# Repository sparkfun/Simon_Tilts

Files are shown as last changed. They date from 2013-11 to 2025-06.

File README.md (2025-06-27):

Simon Tilts - Through Hole Soldering Kit
========================================

[Simon Tilts - Through Hole Soldering Kit  
*Simon Tilts - Through Hole Soldering (KIT-12634)*](https://www.sparkfun.com/products/12634)

This is a new take on the original Simon Says game. Instead of pressing buttons, the player is challenged to tilt the game in a specific pattern of rotations.

Repository Contents
-------------------

* **/Firmware** - Source code, an Arduino Sketch
* **/Hardware** - Eagle design files (Schematic and Board)

License Information
-------------------
The hardware is released under [Creative Commons Share-alike 3.0](http://creativecommons.org/licenses/by-sa/3.0/).  
The firmware is released under beerware license

Hardware author: Pete Lewis @ SparkFun Electonics  
Firmware original author: Pete Lewis @ SparkFun Electronics

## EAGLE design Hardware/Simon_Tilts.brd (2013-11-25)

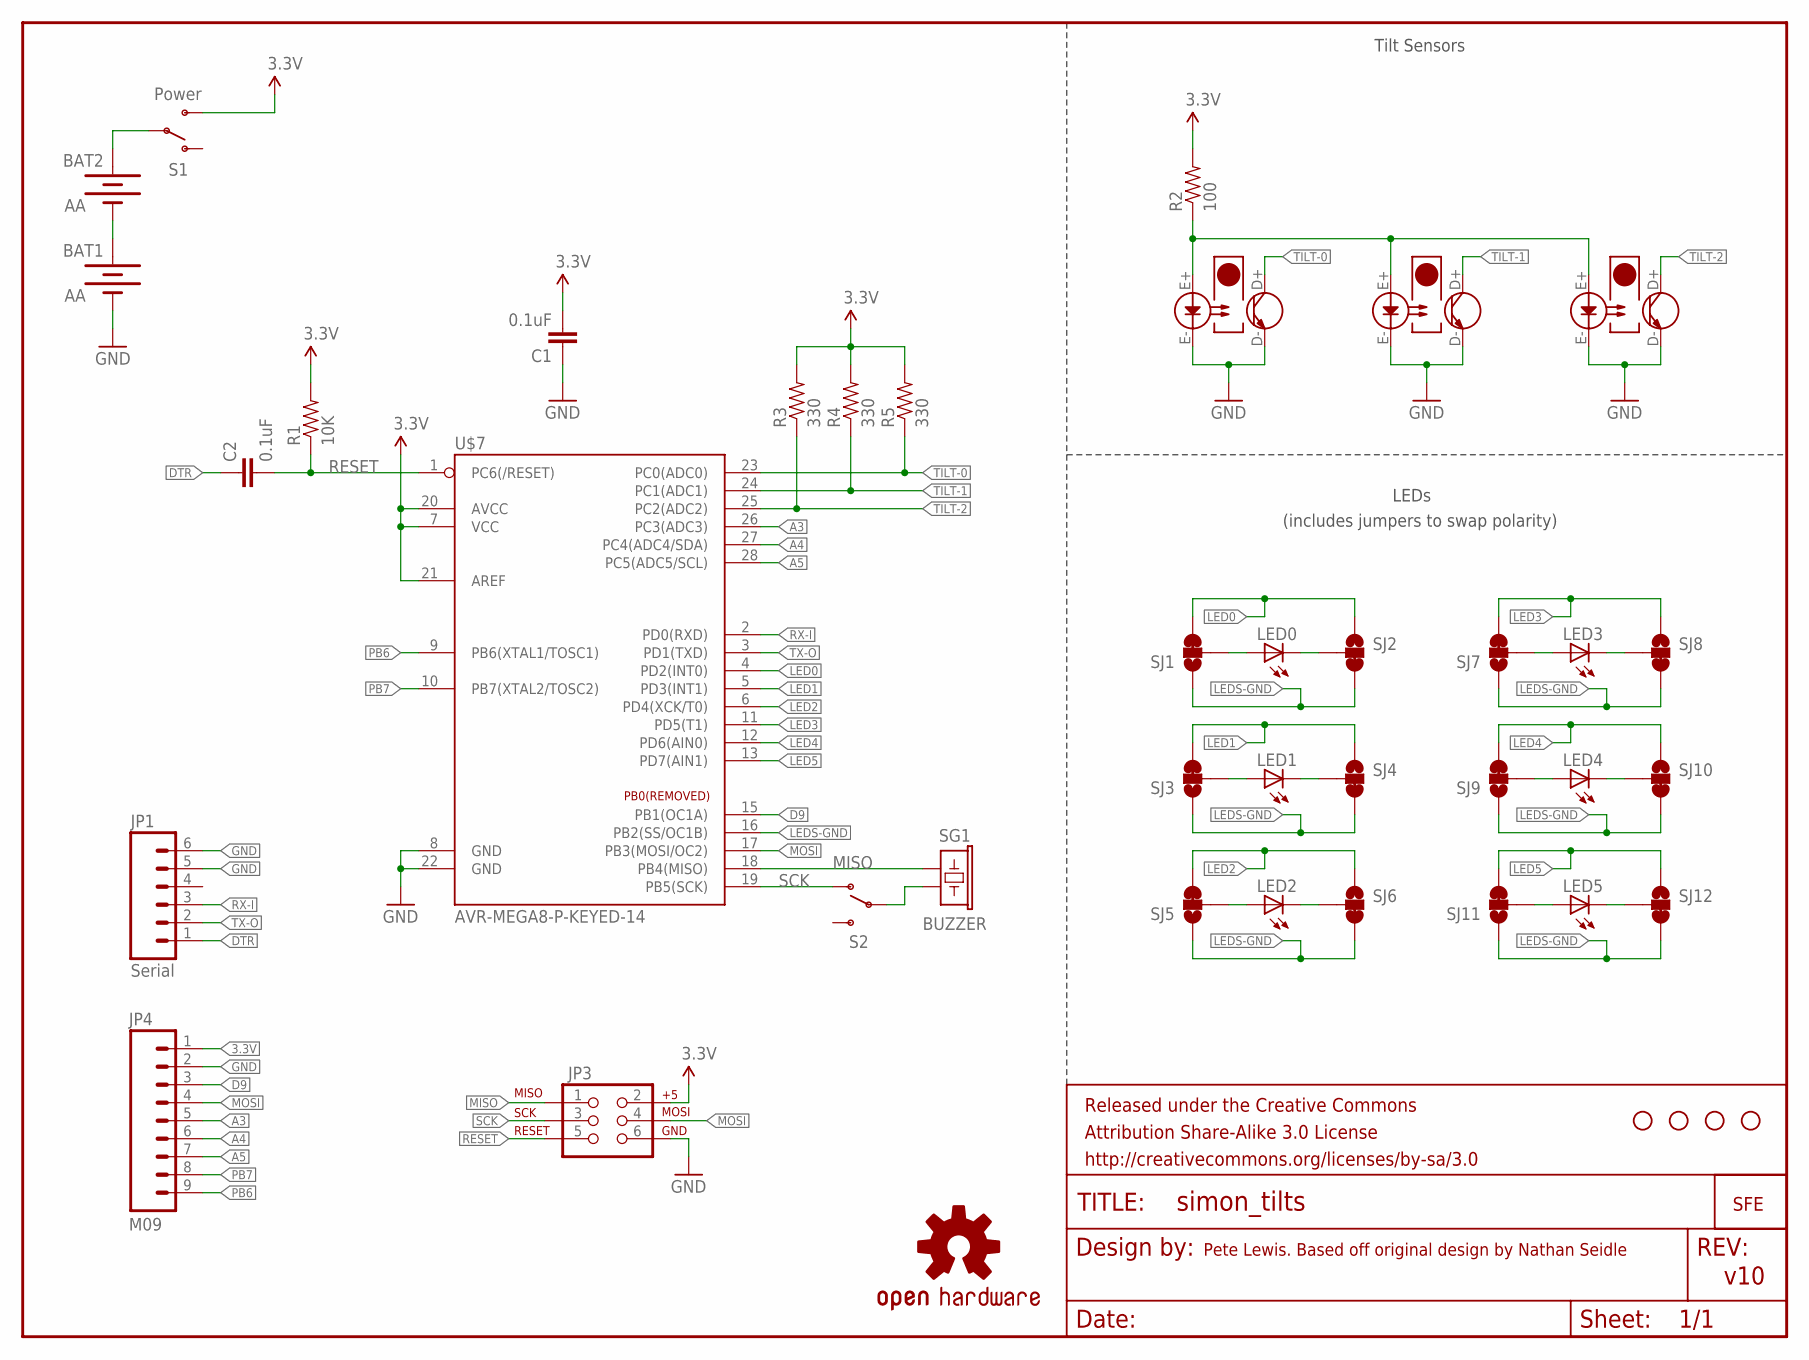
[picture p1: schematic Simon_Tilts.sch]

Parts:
BAT1, BAT2: AA; BATTERY-AA-KIT
C1, C2: 0.1uF; CAP-PTH-SMALL-KIT
FRAME1: FRAME-LETTER; CREATIVE_COMMONS
JP1: Serial; 1X06-NOSILK
JP2, JP5, JP6, JP7: STAND-OFF
JP3: AVR_SPI_PRG_6NS; 2X3-NS
JP4: M09; 1X09
LED0, LED1, LED2, LED3, LED4, LED5: LED5MM-KIT
R1: 10K; AXIAL-0.3-KIT
R2: 100; AXIAL-0.3-KIT
R3, R4, R5: 330; AXIAL-0.3-KIT
S1: Power; SWITCH-SPDT_KIT
S2: SWITCH-SPDTKIT; SWITCH-SPDT_KIT
SG1: BUZZER; BUZZER-12MM-KIT
SJ1, SJ2, SJ3, SJ4, SJ5, SJ6, SJ7, SJ8, SJ9, SJ10, SJ11, SJ12: SOLDERJUMPER_2WAYS; SJ_3
U$1: LOGO-SFENEW; SFE-NEW-WEBLOGO
U$3: OSHW-LOGOS; OSHW-LOGO-S
U$4, U$5, U$6: TILT_SENSORV5; TILT_SENSOR_V5
U$7: AVR-MEGA8-P-KEYED-14; DIL28-3_KEYED-14

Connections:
3.3V: C1.2, JP3.2, JP4.1, R1.P$2 (2), R2.P$2 (2), R3.P$2 (2), R4.P$2 (2), R5.P$2 (2), S1.3 (S), U$7.7 (VCC), U$7.20 (AVCC), U$7.21 (AREF)
A3: JP4.5, U$7.26 (PC3(ADC3))
A4: JP4.6, U$7.27 (PC4(ADC4/SDA))
A5: JP4.7, U$7.28 (PC5(ADC5/SCL))
D9: JP4.3, U$7.15 (PB1(OC1A))
DTR: C2.1, JP1.1
GND: BAT1.GND@1 (-), C1.1, JP1.5, JP1.6, JP3.6, JP4.2, U$4.D-, U$4.E-, U$5.D-, U$5.E-, U$6.D-, U$6.E-, U$7.8 (GND), U$7.22 (GND)
LED0: SJ1.3, SJ2.1, U$7.4 (PD2(INT0))
LED1: SJ3.3, SJ4.1, U$7.5 (PD3(INT1))
LED2: SJ5.3, SJ6.1, U$7.6 (PD4(XCK/T0))
LED3: SJ7.3, SJ8.1, U$7.11 (PD5(T1))
LED4: SJ9.3, SJ10.1, U$7.12 (PD6(AIN0))
LED5: SJ11.3, SJ12.1, U$7.13 (PD7(AIN1))
LEDS-GND: SJ1.1, SJ2.3, SJ3.1, SJ4.3, SJ5.1, SJ6.3, SJ7.1, SJ8.3, SJ9.1, SJ10.3, SJ11.1, SJ12.3, U$7.16 (PB2(SS/OC1B))
MISO: JP3.1, SG1.+ (1), U$7.18 (PB4(MISO))
MOSI: JP3.4, JP4.4, U$7.17 (PB3(MOSI/OC2))
unnamed: LED0.A, SJ1.2
unnamed: BAT2.PWR@1 (+), S1.2
unnamed: S2.2, SG1.- (2)
unnamed: BAT1.PWR@1 (+), BAT2.GND@1 (-)
unnamed: R2.P$1 (1), U$4.E+, U$5.E+, U$6.E+
unnamed: LED0.K (C), SJ2.2
unnamed: LED1.A, SJ3.2
unnamed: LED1.K (C), SJ4.2
unnamed: LED2.A, SJ5.2
unnamed: LED2.K (C), SJ6.2
unnamed: LED3.A, SJ7.2
unnamed: LED3.K (C), SJ8.2
unnamed: LED4.A, SJ9.2
unnamed: LED4.K (C), SJ10.2
unnamed: LED5.A, SJ11.2
unnamed: LED5.K (C), SJ12.2
PB6: JP4.9, U$7.9 (PB6(XTAL1/TOSC1))
PB7: JP4.8, U$7.10 (PB7(XTAL2/TOSC2))
RESET: C2.2, JP3.5, R1.P$1 (1), U$7.1 (PC6(/RESET))
RX-I: JP1.3, U$7.2 (PD0(RXD))
SCK: JP3.3, S2.1 (O), U$7.19 (PB5(SCK))
TILT-0: R5.P$1 (1), U$4.D+, U$7.23 (PC0(ADC0))
TILT-1: R4.P$1 (1), U$5.D+, U$7.24 (PC1(ADC1))
TILT-2: R3.P$1 (1), U$6.D+, U$7.25 (PC2(ADC2))
TX-O: JP1.2, U$7.3 (PD1(TXD))

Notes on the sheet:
v10
Pete Lewis. Based off original design by Nathan Seidle
Tilt Sensors
LEDs
(includes jumpers to swap polarity)

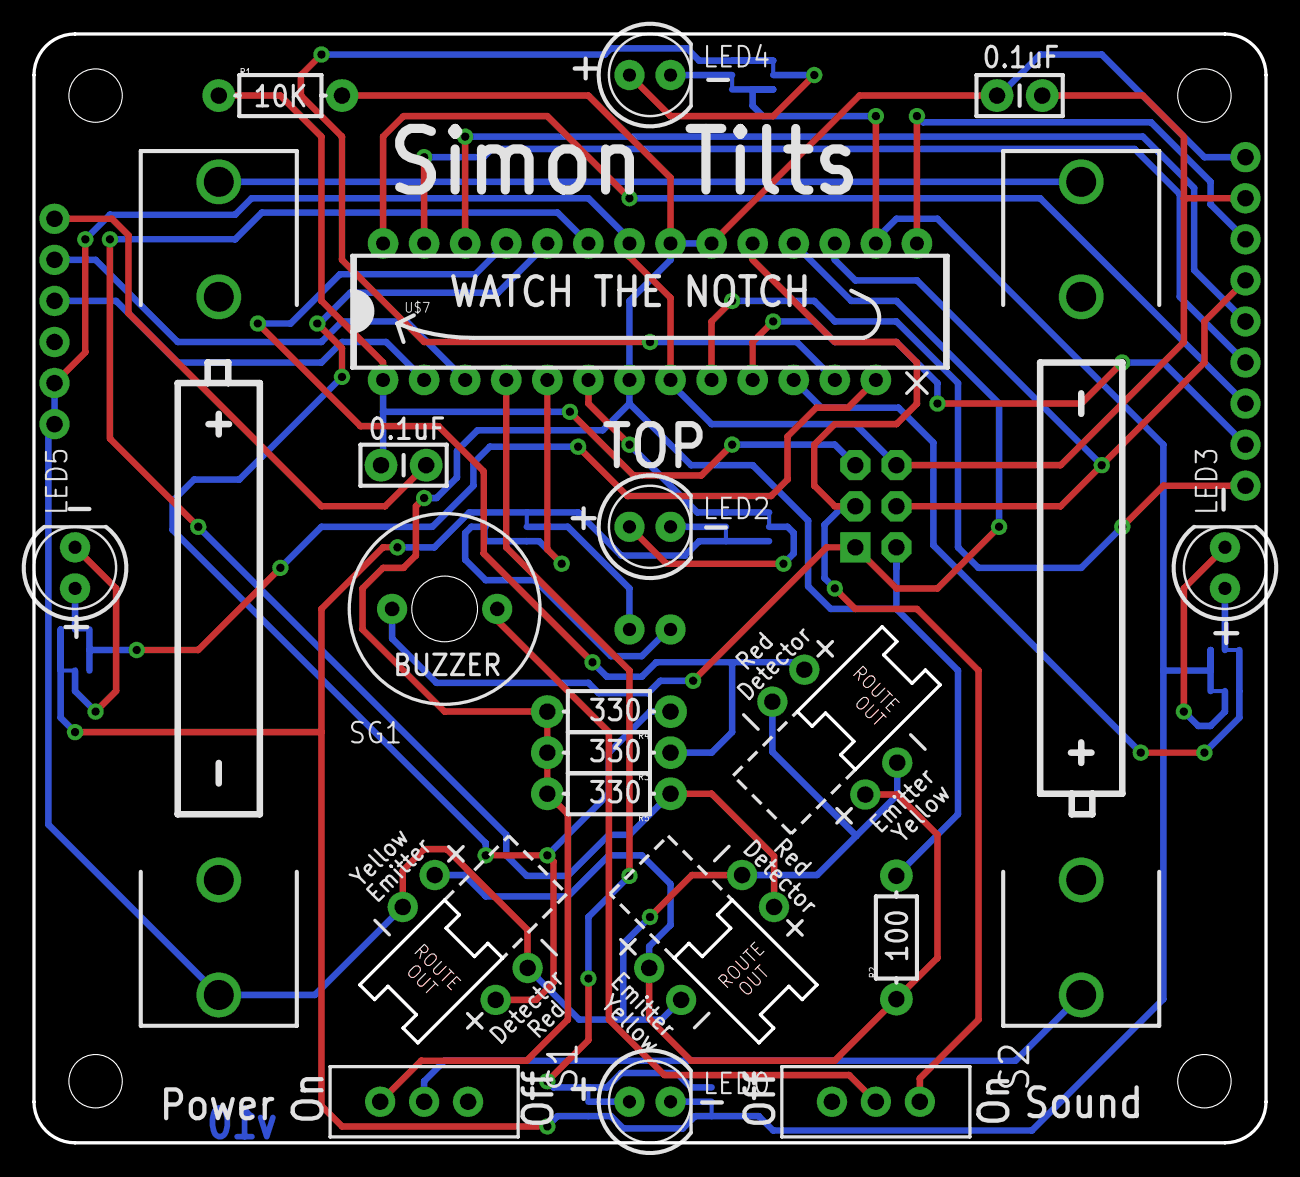
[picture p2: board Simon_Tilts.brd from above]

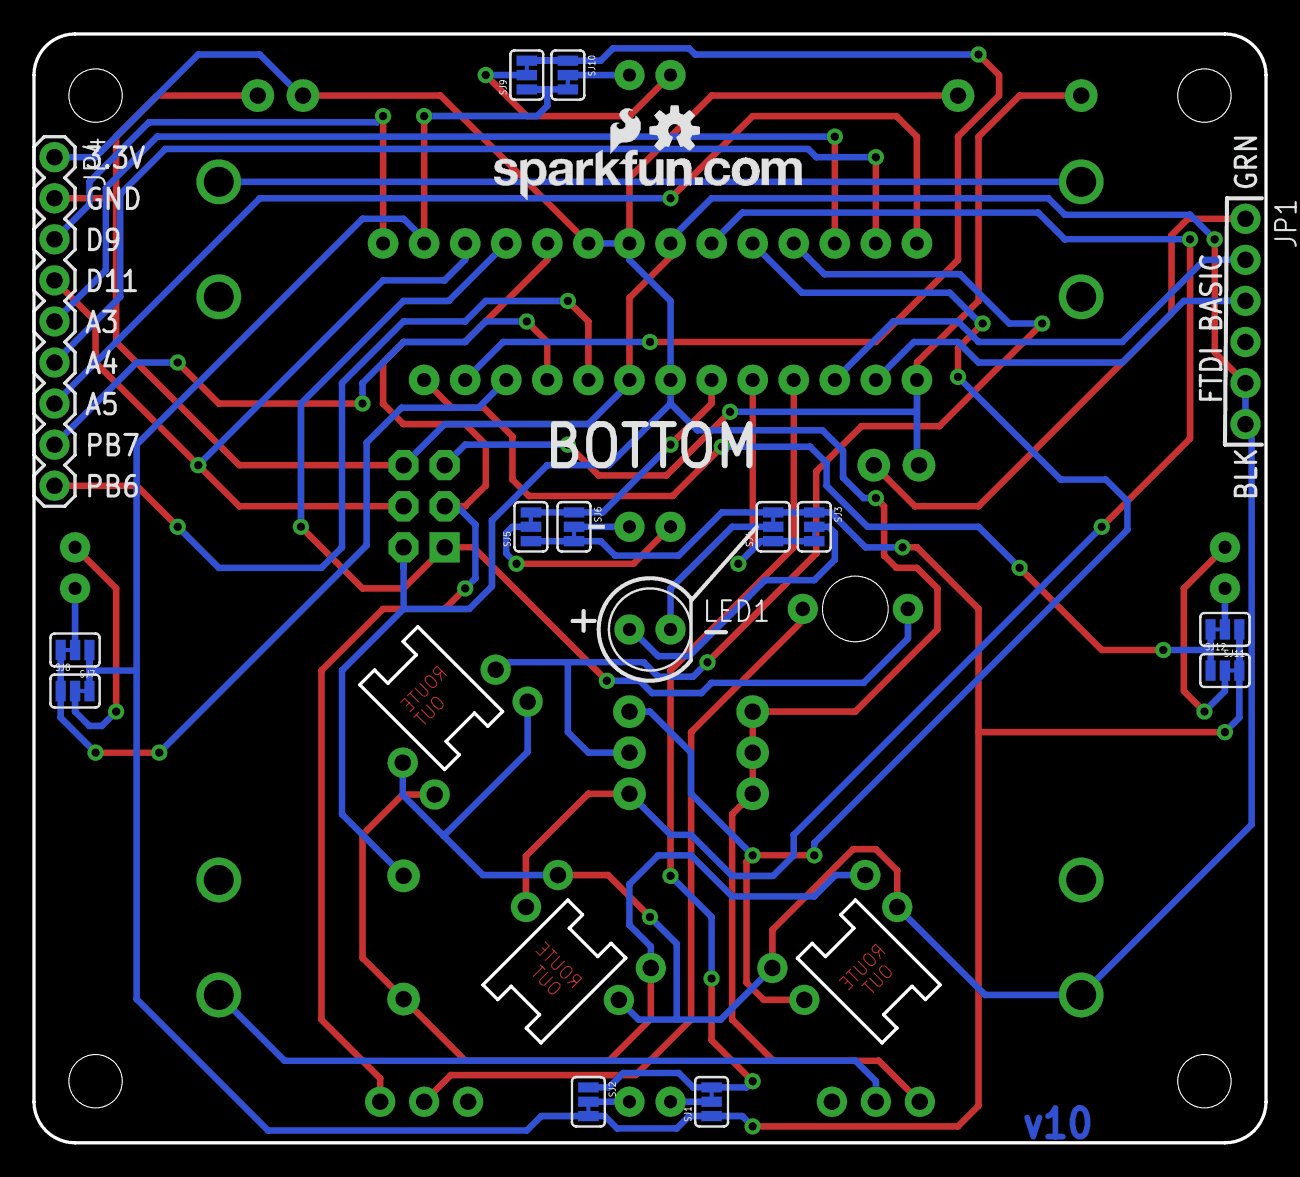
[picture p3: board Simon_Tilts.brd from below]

Board: 2 copper layers, 76.2 x 68.6 mm, 44 parts (18 on the bottom side), 41 nets.

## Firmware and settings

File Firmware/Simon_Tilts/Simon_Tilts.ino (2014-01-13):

/*
*  Simon Tilts
*  Originally written by Pete Lewis January 2014
*  SparkFun Electronics
*  Beerware License. Feel free to use/tweak this, but if you meet me at a bar, 
*  you can buy me a beer.
*  
*  This code is meant to be used with SFE's Simon Tilts thru-hole soldering kit.
*  It can be found here: https://www.sparkfun.com/products/12634
*  
*  It is an educational kit that is not only meant to teach thru-hole soldering,
*  but it also challenges the player to practice memory and orientation skills.
*  
*  This is intended to create a pattern game, similar to the Simon Says, that 
*  involves motion. It uses 3 IR tilt sensors to sense the position of the PCB 
*  in relation to gravity. All 6 sides of the PCB has an LED on it, these are 
*  used to indicate the next tilt direction of the pattern. The buzzer is also 
*  used to associate a tone with each position.
*
*  To start the game, the user must tilt the PCB in any direction. Then repeat 
*  the pattern you see. Remember, tilting an LED upward is the equivalent of 
*  "pressing that button".
*/

#include "pitches.h" // This header file defines the values needed to make 
                     // "scaled" tones on the buzzer

//------------------------------------------------------------------------------
// HARDWARE PIN DECLARATIONS

// Define an array to include the pins for all six LEDs.
  // They are used during gameplay to blink a specific pattern that the player 
  // must follow. They are hardwired in the PCB. This means they will never 
  // change, so they can be a constant int
const int led_pin[6] = {4,2,7,6,5,3}; 

// Define the pin for the GND return on all six LEDs
  // All six LEDs are wired to return on this one single pin: "led_gnd_pin"
  // Most of the time, we will be turning on only one LED at a time
  // To turn on a specific LED, we must turn that LED pin HIGH, and this 
  // led_gnd_pin LOW. We chose pin 10 because it can do PWM. This allows us 
  // to do PWM on all six LEDs
const int led_gnd_pin = 10;

// Define an array to include the pins connected to the tilt sensors
  // Really, they are connected to the infrared detector next to each tilt 
  // sensor. But because their ultimate purpose is to sense tilt position, we 
  // named them "tilt_pin". If we do an analogRead() on these pins, they will 
  // return a different value depending on where the BB is in the tilt arm 
  // sensor. See explanation below for more info.
const int tilt_pin[3] = {14,15,16};

//------------------------------------------------------------------------------
// GAMEPLAY VARIABLE DECLARATIONS

// Define an array to include six NOTES that will be used during gameplay             
  // These notes will be played on the buzzer each time an LED is lite up
  // Each LED gets a specific tone. 
  // This array of notes corresponds with the previous array of LEDs (lede_pin[])
  // These particular notes are a pentatonic scale in D                                      
const int notes[6] = {NOTE_D4, NOTE_F4, NOTE_G4, NOTE_A4, NOTE_C5, NOTE_D5}; 

// Define a boolean to know whether we are in waiting mode or not
  // Simon tilts effectively has three modes (so far): waiting, play, and 
  // nightlight. If nightlight mode is not entered during setup(), then it can 
  // be in "waiting" or "not waiting".
boolean waiting_mode = true;

// Define a variable to keep track of when a player makes a mistake (aka fails)
  // For example, they timed out or rolled to the incorrect position
  // "False" means there is no failure, we will initialize it this way
boolean fail = false;
                  
//------------------------------------------------------------------------------
// LEVEL SPECIFIC VARIABLE DECLARATIONS

// Define a variable to keep track of which level the player is in
  // With each level, the Simon Tilts gets a little more difficult to play
  // The player starts on level 1 and increments up as they complete each level
  // See function set_level_variables() for more info
int level = 1;
               
// Define playback_delay_time variable (MILLISECONDS)
  // This affects the overall speed at which the pattern is shown to the player
  // The pattern may be as little as one (and as many as 20) "steps"
  // This variable is the amount of milliseconds delay in between each step's 
  // blink. In level one, the delay time is 400 ms (pretty slow). It will decrease
  // more and more in higher levels. See function set_level_variables() for more 
  // info.
int playback_delay_time; 

// Define a variable to keep track of how many moves it takes to win the current 
// level
  // It starts with 5, then it get's longer with each level
  // See function set_level_variables() for more info
int moves_to_win; 

// Define an array to keep track of the game pattern
  // The game pattern is the sequence of tilt positions that the user must repeat
  // It is randomly chosen each time the user enters a new level
  // Each level, it gets longer and longer.
  // This means it could get as long as 23 on level 10.
  // It is *really* hard to complete level 3, so I'd be very excited to see 
  // someone win level 10 and break this array. For most players they will only 
  // be using the first 9 spots of this array and then failing :)
int game_pattern[23] = {};

// Define a variable to keep track of the length of the current game
  // This is the number of tilt positions in the pattern the user must repeat in 
  // order to advance each "partial-level". It is incremented each time there is 
  // a new random position added to game_pattern[]. It is also compared with 
  // moves_to_win each time the player tilts correctly. This is how we know if 
  // the player has one the level yet, or if they are still building to 
  // moves_to_win.
int game_length = 0;                      

// Define an array to include the next possible positions that could be added to 
// the game pattern.
  // This is necessary, so that when we randomly choose a pattern, it doesn't 
  // choose two of the same positions in a row. Because this is a tilt motion 
  // game, it doesn't make sense if the pattern repeats on the current position.
  // We also use this array in combination with the function, 
  // lookup_possible_positions(), in order to make the game pattern more user 
  // friendly for levels 1 and 2. We can ensure that the game pattern always moves
  // from one position to an adjacent position, and not an "across" position 
  // (i.e. if you're on the top, then immediately blinking the bottom).
  // See lookup_possible_positions() for more info.
int next_possible_positions[4] = {};

//------------------------------------------------------------------------------
// TILT SENSOR SPECIFIC VARIABLE DECLARATIONS

// Infrared tilt sensor explanation
// The tilt sensors are little tubes with small metal ball bearings (aka "BB"s) 
// in them. Each BB can fall to either end of the tube, and is pulled by gravity.
// On one end of the tube (closest to the PCB) there is a "look through" hole.
// With an IR emitter and detector on either side of the "look through" hole,
// we can see if the BB is present or not.
// Combining three of these tilt sensors positioned carefully, you can sense 
// 6 positions: TOP, BOTTOM, LEFT, RIGHT, FRONT, BACK (these are defined while 
// holding the game so that the silk "SIMON TILTS" reads left to right, and is 
// facing upwards)

// The readings from each IR detector are as follows for each position
// Each infrared detector is defined by it's corresponding pin on the micro 
// (it's "tilt_pin")

//   POSITION     tilt_pin[0]    tilt_pin[1]    tilt_pin[2]       DECIMAL
//------------------------------------------------------------------------
//   TOP          1              1              1                 7 
//   BOTTOM       0              0              0                 0
//   LEFT         1              0              1                 5
//   RIGHT        0              1              0                 2
//   FRONT        1              0              0                 4
//   BACK         0              1              1                 3

// Define an array of "good" readings from the tilt sensors
  // Notice how 1 and 6 are not included as possibilities in the table above.
  // This is because of the particular angle and placement of the tilt arms.
  // 1 and 6 are impossible, so in an effort to debounce the data, we create the 
  // following array. The order of this array is important, because it 
  // corresponds with the led_pin[] array.
const byte correct_tilt_byte[6] = {7,4,5,3,2,0};

// Define a variable used to store the actual current physical position
  // This is determined by which tilt position the player is currently holding 
  // the game. It is updated every time we call read_position_w_debounce().
  // It is also used in listen_for_pattern() to determine gameplay.
int current_tilt_position;

void setup()
{
  Serial.begin(57600); // For debugging
  randomSeed(analogRead(A7)); // We use random() to create the unique game 
                              // pattern for each level.
                              // This seed helps make it "more" random
  // LED SETUP 
    // Turn all six to OUTPUTS
  for(int i = 0;i<6;i++)
  { 
    pinMode(led_pin[i], OUTPUT);
  }
  
  // Turn the GND return for all six leds to output, and low
  pinMode(led_gnd_pin, OUTPUT);
  digitalWrite(led_gnd_pin, LOW);
  // Blink all Leds 3 times to show that they are working 
  blink_all(100);
  blink_all(100);
  blink_all(100);
  
  //  BUZZER SETUP
    // The Buzzer is connected to pins 12 and 13
    // Turn both to outputs
  pinMode(12,OUTPUT);
  pinMode(13,OUTPUT);
  // Write the "pin 13 side" LOW
  // We will use the "pin 12 side" to buzz the tone
  digitalWrite(13,LOW);

  // EASTER EGG!!! -- CHECK FOR NIGHTLIGHT MODE --
    // If the user turns on the game while holding it upside down, 
    // then it will go into a special mode called "Nightlight mode"
    // This is in setup() because we only want it to check once (right after 
    // powering up). If the game is held in any other position, then it will 
    // continue into the main loop and play default game mode.
    // To enter night light mode, follow these three steps:
    // 1. Turn game off
    // 2. Hold game upside down
    // 3. While continuing to hold game upside down, turn the game back on again 
    //    and wait a moment.
  if(read_position_once() == 0) // read_position_once() will return a "0" if the 
                                // game is held upside down
  {
    while(1) // Stay in nightlight mode forever (or at least until you cyle power) 
    {
      nightlight_fade(random(0,6)); 
    }
  }
}

void loop()
{
  // Each time we come around to the beginning of the main loop, check to see if 
  // we want to be in waiting mode. If waiting mode is engaged, then we will 
  // enter the following while loop and wait for the player to move the game in 
  // any way, to indicate they want to start a new game.
  // When "waiting_mode" is set to false, then this while loop is ignored and 
  // normal game play happens.
  // "waiting_mode" is only changed to false in wait_for_user_input_change()
  while(waiting_mode) wait_for_user_input_change();
  
  set_level_variables(level); // this adjusts moves_to_win, game_length, 
                              // and playback_delay_time
  
  if(fail == true){
    Serial.println("Starting Over...");
    randomSeed(analogRead(A7));
    fail = 0;
  }
  
  game_length++;
  Serial.print("game_length:");
  Serial.println(game_length);
  
  // Look up possible positions
  // the "gamelength-1" means were looking at the last position added 
  // (not the one were trying to add).
  lookup_possible_positions(game_pattern[game_length-1]); 
  
  // Remember the step 1 (aka the second step of pattern)
  // We will use it below to ensure we never have the same first and second step
  // This helps keep the pattern different each time.
  int previous_game_pattern_1 = game_pattern[1]; 
                                                                        
  game_pattern[game_length] = next_possible_positions[random(0,4)];

  if(game_length == 1) // help avoid doing the same pattern as previous game
  { 
    while(game_pattern[game_length] == previous_game_pattern_1)
    {
      // keep pulling new random positions, until it doesn't equal the previous 
      // pattern step 1
      game_pattern[game_length] = next_possible_positions[random(0,4)]; 
    }
  }
  
  // If we're at level 3+, add a second pattern, this means we get two 
  // added after each "user repeat"
  if(level >= 3) 
  {
    game_length++;
    game_pattern[game_length] = random(0,6); // no rules, 
    // i.e. it can grab any next position it likes (i.e. the "across LED")
    if(game_pattern[game_length] == game_pattern[game_length-1])
    {
      // prevent two of the same in a row
      while(game_pattern[game_length] == game_pattern[game_length-1]) 
      {
        game_pattern[game_length] = random(0,6); 
      }
    }
  }
  
  if(game_length == 0) game_length = 1; // always have at least 1 in the length
  
  show_game_pattern();
  
  Serial.print("Get Ready, GO!!");
  
  listen_for_pattern(); // Listen for correct pattern (handles timeout and 
  // failures). Because gamelength and moves_to_win are global, it knows when 
  // you've won or lost
}

// Define a function to take lots of readings from the tilt sensors and debounce 
// them into one usable position reading #
  // This is a bit different than your standard averaging debounce of streaming 
  // data. In fact, it doesn't do any averaging at all.
  // We make an array to store all the streaming readings.
  // We then starting filling the array with one reading at a time.
  // There are two important things going on with this function:
  // (1) it compares each new reading with the previous reading,
  // If they are the same, then it stores the active reading and moves on to take 
  // another. If it's different, then it doesn't take it as a good reading, and 
  // assumes it's noise.
  // The for loop ends and the reading doesn't change current_tilt_position. 
  // So essentially, this reading failed (it was too noisy).
  // This makes the player actually hold the game still for 50 readings 
  // (which is actually only a few mili seconds).
  // (2) It compares each reading to correct_tilt_byte[] array.
  // This makes sure that the BBs are settled in the tilt arm and not causing an 
  // erroneous data. It converts the raw byte returned from read_position_once() 
  // into a number from 0 to 6. This will be the ultimate position #. It is more 
  // useful this way, because we can use it to call the corresponding LED from 
  // led_pin[] array.
void read_position_w_debounce()
{
  int pos_array[100]; // used to store position readings in a row. 
  // We want to make sure that the position has stayed there for at least 
  // 50 readings before we make it a new reading.
  int valid_reading = 0;
  for(int j = 0;j<50;j++)
  {
    // Take a single reading from the tilt sensors.
    byte raw_tilt_input = read_position_once(); 
    // Compare the raw reading to the "known goods" in the correct_tilt_byte[] 
    // array. Do it in a for loop so we can check all six.
    for(int i = 0;i<6;i++) 
    {
      if(raw_tilt_input == correct_tilt_byte[i]) 
      {
        // Convert to a number from 0 to 6 (i from this for loop will be 0-6), 
        // this will be our ultimate # to know the position.
        pos_array[j] = i; 
        Serial.print(pos_array[j]);
        break;
      }
    }
    
    // We will assume the first reading is always a valid reading.
    // This keeps the total count correct.
    if(j == 0) valid_reading += 1; 
    else{
      // check new reading against previous, if it's the same, increment 
      // valid_reading
      if(pos_array[j] == pos_array[j-1]) valid_reading += 1; 
      else{
        delay(100);
        j=50;
      }
    }
  }
  Serial.print("--");
  Serial.println(valid_reading);
  
  // only if we get 50 valid readings (all the same), do we take this as a 
  // solid good reading. And finally... set the current_tilt_position to the 
  // first reading in the array, pos_array[0].
  if(valid_reading == 50) current_tilt_position = pos_array[0]; 
                                                                
}


// Define a function that listens for the correct pattern to be rotated by the 
// player
  // This is basically a for loop that goes through the current gamelength,
  // and listens for the player to tumble the correct pattern
  // It includes a timeout by rapping all of the "if's" in a while(timeout<50)
  // In each of the IF statements it checks 
  // (1) Are they on the correct next position?
  // (2) Is it time to timeout?
  // (3) Are they still on the previous position?
  // (4) Did the player rotate to the wrong position? 
  // (5) Has the player stayed on a wrong position for 15 counts?
void listen_for_pattern()
{
  for(int i = 1; i<=game_length;i++)
  {
    int timeout = 0;
    int wrong_positions = 0;
    while(timeout<50)
    {
      read_position_w_debounce(); // Take in a reading of position with debounce
      
      // (1) Are they on the correct next position?
      if(current_tilt_position == game_pattern[i]) 
        {
          // Blink current position once to indicate they did it correctly
          blink_led_w_fade(current_tilt_position); 
          break;
        }
        
      // (2) how long have they been trying (or thinking), is it time to timeout?
      else if ((timeout == 49)) 
      {
        Serial.print("Timed out on position ");
        Serial.println(i);
        blink_player_timed_out();
        waiting_mode = true;
        game_length = 0; // this gets us out of listen_for_pattern()
        level = 1;
        fail = 1;
        break;
      }
      
      // (3) Are they still on the previous position? 
      // If so, do nothing and increment timeout (happens below)
      else if(current_tilt_position == game_pattern[i-1]); 
      
      // (4) Did the player rotate to the wrong position? 
      //  If so, keep track of how long by incrementing "wrong_positions"
      else if(current_tilt_position != game_pattern[i]) wrong_positions += 1; 
                                                                            
      // (5) Has the player stayed on a wrong position for 15 counts?
      if(wrong_positions > 15) 
      {
        Serial.print("you tumbled wrong:");
        Serial.println(current_tilt_position);
        // Blink quickly to show the incorrect tilt position
        blink_led(current_tilt_position, 50); 
        blink_all(50);
        // Blink where the player should have rolled to
        blink_led(game_pattern[i], 100); 
        delay(10);
        // Blink where the player should have rolled to (again)
        blink_led(game_pattern[i], 100); 
        delay(10);
        // Blink where the player should have rolled to (and  a 3rd time)
        blink_led(game_pattern[i], 400); 
        game_length = 0; // this gets us out of listen_for_pattern()
        level = 1;
        fail = 1;
        waiting_mode = true;
        break;
      }
      timeout += 1;   // Increment timeout
   } // End of timeout while loop
  
   if((i == game_length) && (fail == false))
   {
     Serial.println("current gamelength complete!");
     Serial.println(current_tilt_position);
     delay(250);
     // Check to see if the player has reached "moves_to_win"
     if(game_length == moves_to_win)
     { 
       show_winner_blinkies(); // you've won!!
       game_length = 0; // this gets us out of listen_for_pattern()
       fail = 1;
       level += 1; // go to next level
     }
     else{
       delay(1000); // delay to give the player time to be ready for playback
     }
    }
  } // end of game pattern for loop
}


// Define a function to blink one LED for a set amount of time with sound
  // Send this an LED number (0-5) and a delay time (milliseconds)
  // This function is only used in listen_for_pattern()
  // It is used when a player rotates to the incorrect position
  // and Simon Tilts then wants to show you where you should have rotated to.
void blink_led(int num, int delay_time)
{
  tone(12, notes[num]);
  digitalWrite(led_gnd_pin, LOW);
  digitalWrite(led_pin[num], HIGH);
  delay(delay_time);
  noTone(12);
  digitalWrite(led_gnd_pin, HIGH);
  digitalWrite(led_pin[num], LOW);
  delay(delay_time);
}


// Define a function to "blink" an led with quick fading and sound
  // This is used during playback of the game sequence
  // Send it a number and it will fade in and out quickly on that LED
void blink_led_w_fade(int num)
{
  tone(12, notes[num]);
  digitalWrite(led_gnd_pin, HIGH);
  digitalWrite(led_pin[num], HIGH);
  
  // fade out from max to min in increments of 40 points:
  for(int fadeValue = 255 ; fadeValue >= 0; fadeValue -=40) 
  {
    analogWrite(led_gnd_pin, fadeValue); // sets the value (range from 0-255):  
    delay(30); // wait for 30 milliseconds to see the dimming effect   
  } 
     
  for(int fadeValue = 0 ; fadeValue <= 255; fadeValue +=70) 
  { 
    analogWrite(led_gnd_pin, fadeValue); // sets the value (range from 0-255):      
    delay(30); // wait for 30 milliseconds to see the dimming effect                           
  } 
  digitalWrite(led_pin[num], LOW);
  digitalWrite(led_gnd_pin, LOW);
  noTone(12);
}


// Define a function to blink all six LEDs in sequence without sound
  // This basically uses a for loop to blink all six LEDs
  // It does NOT buzz the buzzer with each corresponding tone
void blink_all(int delay_time)
{
  digitalWrite(led_gnd_pin, LOW);
  for(int i = 0;i<6;i++)
  { 
    digitalWrite(led_pin[i], HIGH);
    delay(delay_time);
    digitalWrite(led_pin[i], LOW);
  }
}
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

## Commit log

2013-11-07 Initial commit of hardware, firmware, gitignore, and cleanup batch file
    Hardware v01 ready for protos
    [Simon_Tilts.brd, Simon_Tilts.sch]
2013-11-25 V10 ready for red boards
    -Updated tilt sensor package to TILT_SENSOR_V5, then rerouted irregular
    traces.
    -Changed version to "V10" in bottom copper AND schematic.
    [Simon_Tilts.brd, Simon_Tilts.sch]
2013-11-28 Updated game play rules
    added "waiting mode", the player must tilt the game in any way to engage
    starting the game.
    Also changed it so the first tilt is always a side LED, this is more
    intuitive for game play. This way you don't have to explain the "first
    tilt is free thing".
2014-01-10 fixing line widths
    about half way done
    [Simon_Tilts.ino]
2014-01-13 line widths and more
    -Reduced remaining line widths of comments
    -Fixed comment about tilt sensor explanation (impossibilities) to 1 and
    6, (not 5 and 6)
    -changes comparisons to fail (a boolean variable ) to false/true rather
    than "0" and "1"
    [Simon_Tilts.ino]

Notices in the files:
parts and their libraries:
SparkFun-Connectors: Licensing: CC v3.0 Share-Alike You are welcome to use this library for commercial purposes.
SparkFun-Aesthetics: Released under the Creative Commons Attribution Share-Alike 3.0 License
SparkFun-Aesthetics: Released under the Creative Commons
